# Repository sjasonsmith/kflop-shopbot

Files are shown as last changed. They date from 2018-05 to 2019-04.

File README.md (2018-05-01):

# kflop-shopbot
Custom KFLOP operations for a repowered ShopBot Buddy with speed controlled spindle.

**Caution: These scripts are not guaranteed to work on your machine.
Use at your own risk, and only with a full understanding of the functionality you are using.**

These scripts were developed for a ShopBot Buddy which has been repowered with a Dynomotion KFLOP Motion Controller. Refer to the following forum for a description of the conversion:

https://www.cnczone.com/forums/dynomotion-kflop-kanalog/310688-software.html

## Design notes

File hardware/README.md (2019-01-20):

# kflop-shopbot
EAGLE resources to create an interface board between the KMotion KFlop and the ShopBot Buddy.
This enables the conversion without modifying any existing electronics.

Board layout
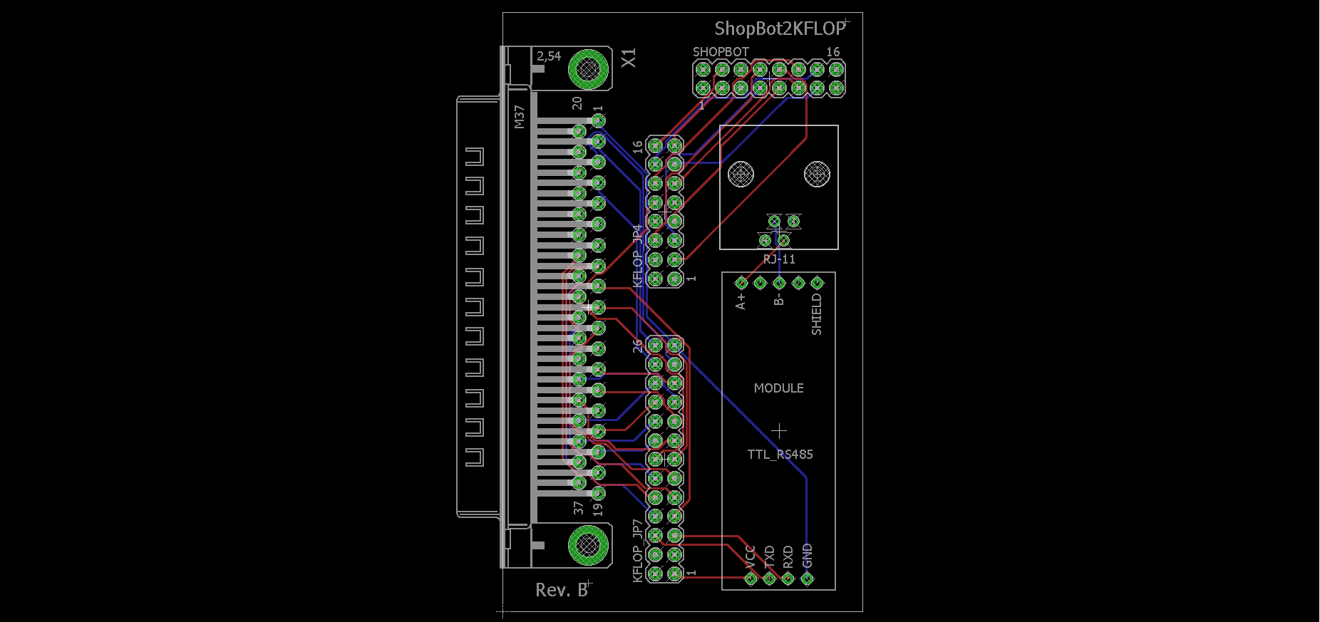
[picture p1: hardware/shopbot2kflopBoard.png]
Board Layout Image


Schematic
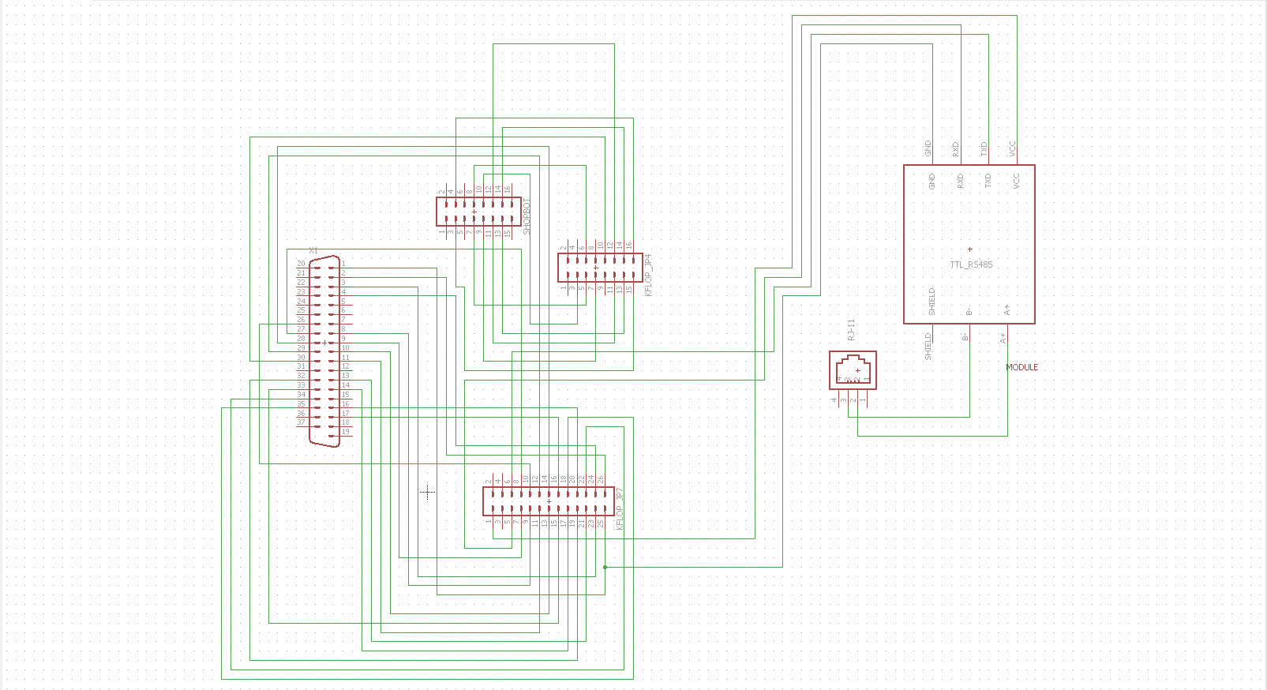
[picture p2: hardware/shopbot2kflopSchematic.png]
Schematic Image


Additional Information:

https://www.cnczone.com/forums/dynomotion-kflop-kanalog/310688-software.html

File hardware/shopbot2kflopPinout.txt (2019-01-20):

DB-37 Pin	Description           KFlop JP7 Pin	Description
-------------------------------------------------------------------
1		Ground			25		GND
2		Ground			26		GND
3		5V			23		VDD5
4		5V			24		VDD5
8		Input 3 (Y-Home)	9		IO2
9		Input 1 (Probe)		7		IO0
10		Input 7			13		IO6
11		Input 5 (Z-Home)	11		IO4
13		Step 4 (A-Axis)		21		IO14/STEP3
14		Step 2 (Y-Axis)		17		IO10/STEP1
16		Direction 3 (Z-Axis)	20		IO13/DIR2
17		Direction 1 (X-Axis)	16		IO9/DIR0
26		Input 4 (E-Stop)	10		IO3
27		Input 2 (X-Home)	8		IO1
28		Input 8			14		IO7
29		Input 6			12		IO5
30		All Windings Off	JP4 10		IO19 LVTTL
32		Step 3 (Z-Axis)		19		IO12/STEP2
33		Step 1 (X-Axis)		15		IO8/STEP0
34		Direction 4 (A-Axis)	22		IO15/DIR3
35		Direction 2 (Y-Axis)	18		IO11/DIR1

Left Ribbon 	Description           KFlop JP4 Pin	Description
-------------------------------------------------------------------
3  - Output 9					JP4 15	IO24 LVTTL
4  - Output 10					JP4 16	IO25 LVTTL
7  - Output 1 (Spindle 1 Relay Control)		JP4 5	IO16 LVTTL
8  - Output 2 (Spindle 2 Relay Control)		JP4 6	IO17 LVTTL				
9  - Output 3					JP4 7	IO18 LVTTL
10 - Output 4 (Master Spindle Relay Control)    JP4 3	VDD33 
11 - Output 5					JP4 11	IO20 LVTTL
12 - Output 6					JP4 12	IO21 LVTTL
13 - Output 7					JP4 13	IO22 LVTTL
14 - Output 8					JP4 14	IO23 LVTTL

RS-485 		Description           KFlop JP7 Pin	Description
--------------------------------------------------------------------
GND		Ground			JP7 25		GND
RXD		Receive			JP7 5		IO44 LVTTL UART
TXD		Transmitt		JP7 6		IO45 LVTTL UART
VCC		Vcc			JP7 1		VDD33

Universal CNC 4 Axis MPG - NOT PROOFED
Wire	Color		Function		Kflop JP6	
---------------------------------------------------------------------
1	Red		+5V MPG			1	VDD5	+5 Volts Output
2	Black		GND MPG			8	GND	Digital Ground
3	Yellow		A+ signal MPG		5	IO26 	Gen Purpose LVTTL I/O
4	Light Yellow	A- signal MPG
5	White		B+ Signal MPG		6	IO27 	Gen Purpose LVTTL I/O
6	Transparent	B- Signal MPG
7	Light red	LED +
8	Gray		LED -
9	Brown		X Axis select		7	IO28 	Gen Purpose LVTTL I/O
10	Orange		Y Axis select		10	IO29 	Gen Purpose LVTTL I/O
11	Light blue	Z Axis select		11	IO30 	Gen Purpose LVTTL I/O
12	Blue		4 Axis select
13	Dark green	X 1 Select		12	IO31 	Gen Purpose LVTTL I/O
14	Green		X10 Select		13	IO32 	Gen Purpose LVTTL I/O
15	Light green	X100 Select		14	IO33 	Gen Purpose LVTTL I/O
16	Purple		COM select		8	GND	Digital Ground
Shield			Shield wire
estop?						15	IO34 	Gen Purpose LVTTL I/O
estop?						16	IO35 	Gen Purpose LVTTL I/O

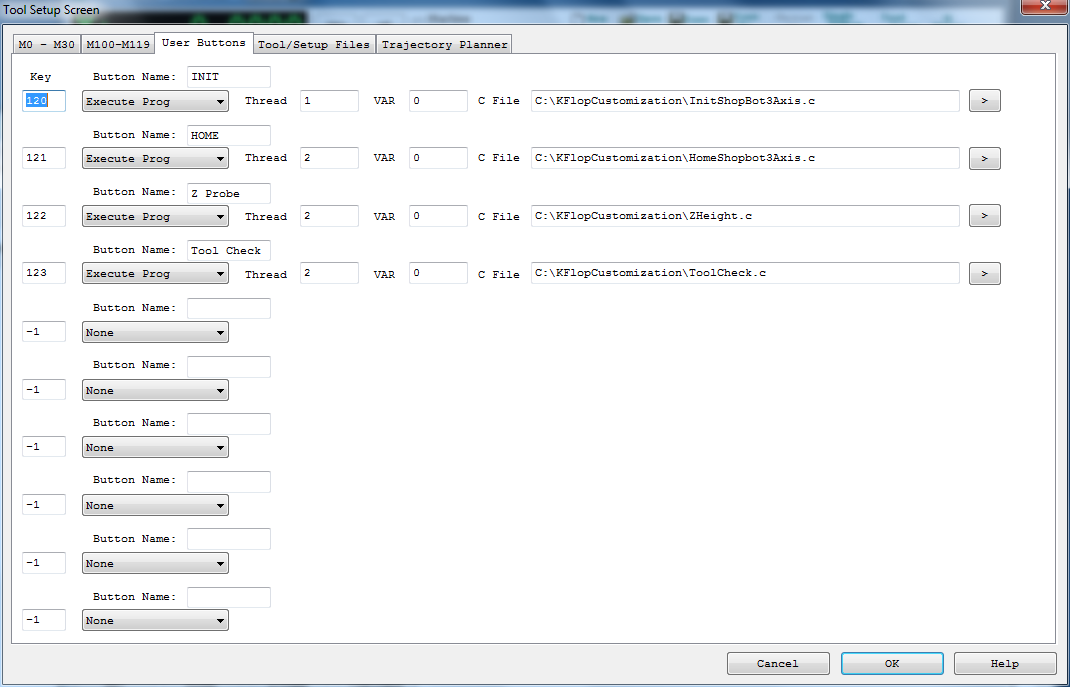
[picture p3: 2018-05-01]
images/UserButtons.PNG

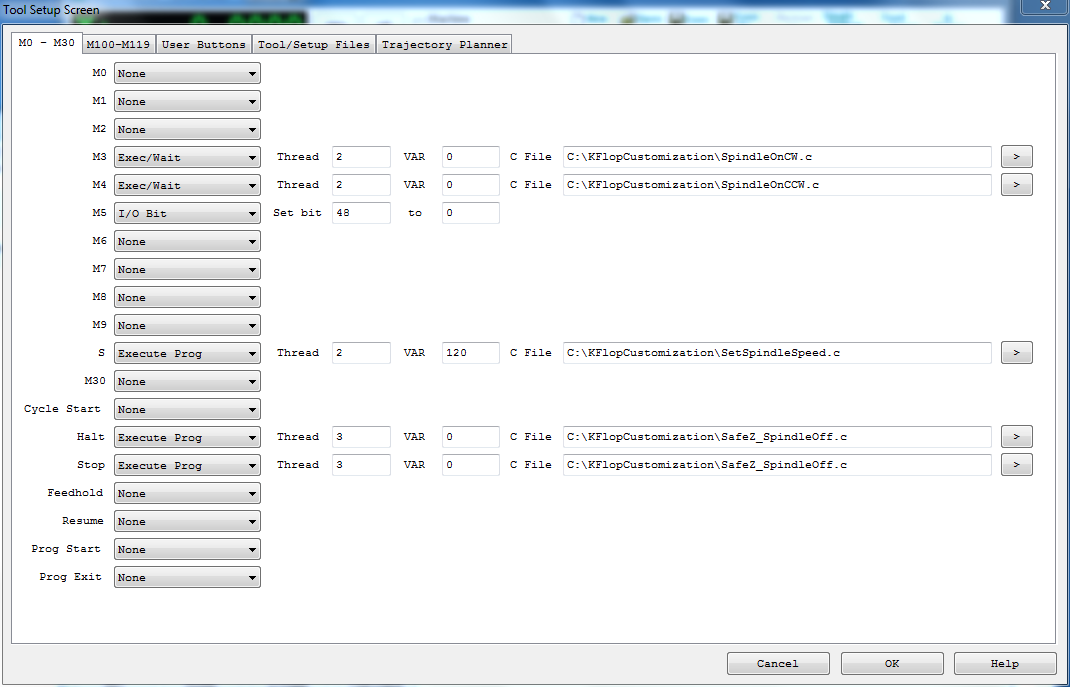
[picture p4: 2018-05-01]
images/M0-M30.PNG

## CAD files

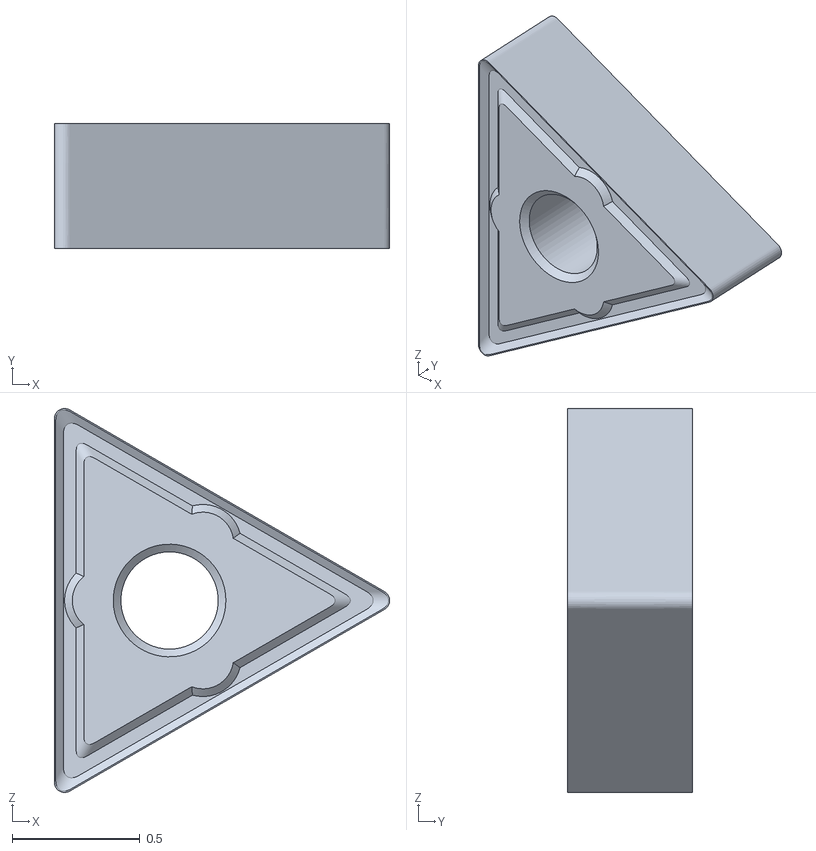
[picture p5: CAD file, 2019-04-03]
KMotionDataSnapshot/ToolImages/TNMG.obj
1.31 x 0.49 x 1.50

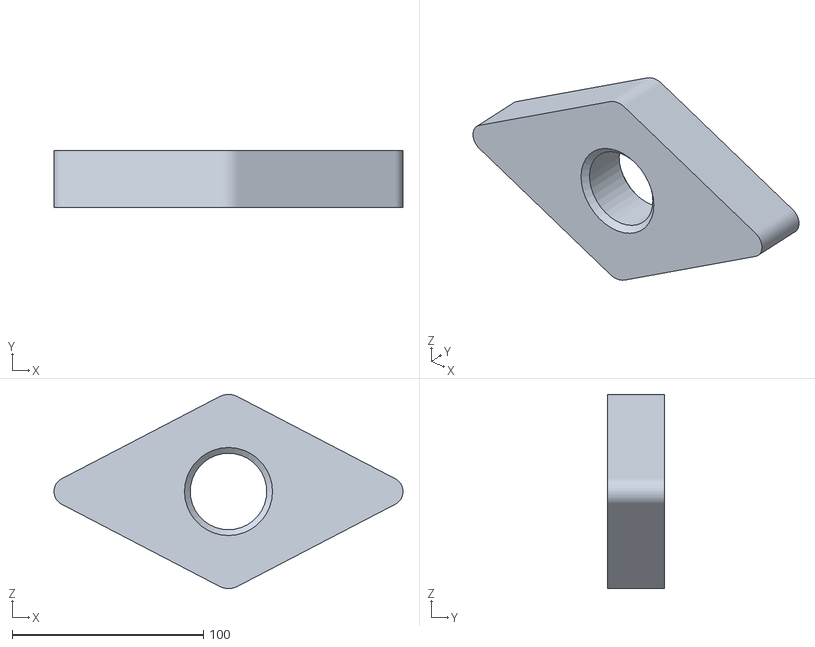
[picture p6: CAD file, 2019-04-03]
KMotionDataSnapshot/ToolImages/DCGT-1.obj
182.5 x 30.0 x 101.6

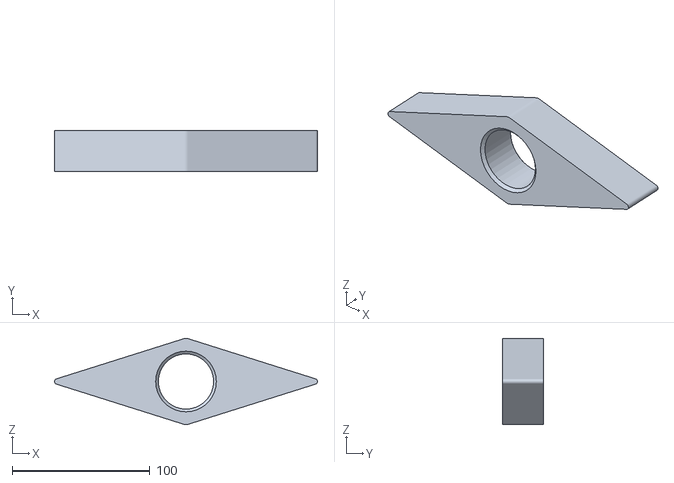
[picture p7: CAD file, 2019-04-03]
KMotionDataSnapshot/ToolImages/VNMG-1.obj
190.7 x 30.0 x 62.6

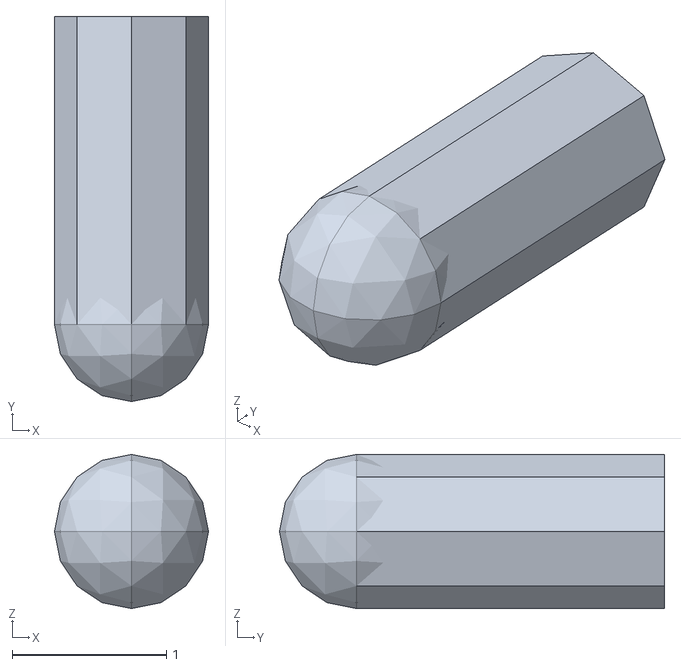
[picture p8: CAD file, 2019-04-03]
KMotionDataSnapshot/ToolImages/tooly.obj
1.00 x 2.50 x 1.00

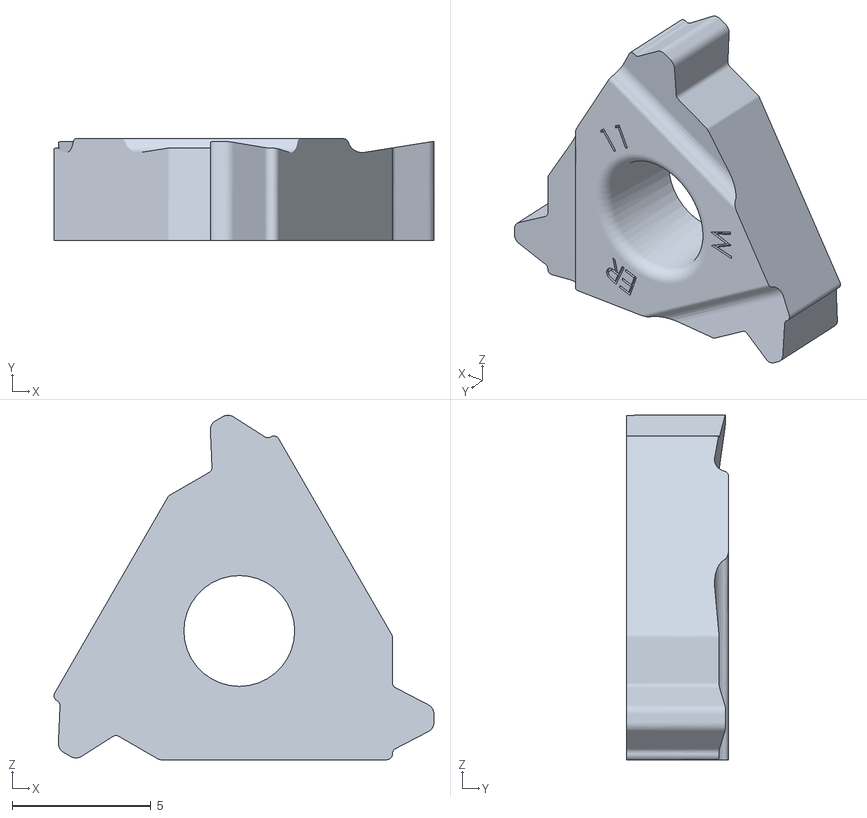
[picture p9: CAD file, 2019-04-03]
KMotionDataSnapshot/ToolImages/NPTF Front.obj
13.7 x 3.68 x 12.4

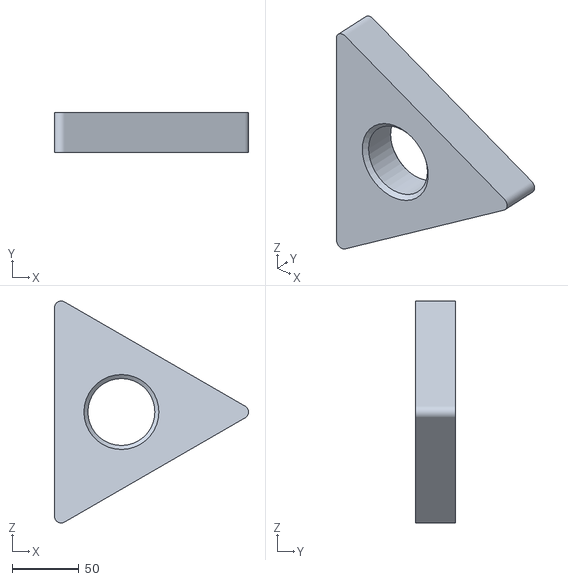
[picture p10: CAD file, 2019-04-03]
KMotionDataSnapshot/ToolImages/TNMG-1.obj
145.0 x 30.0 x 165.9

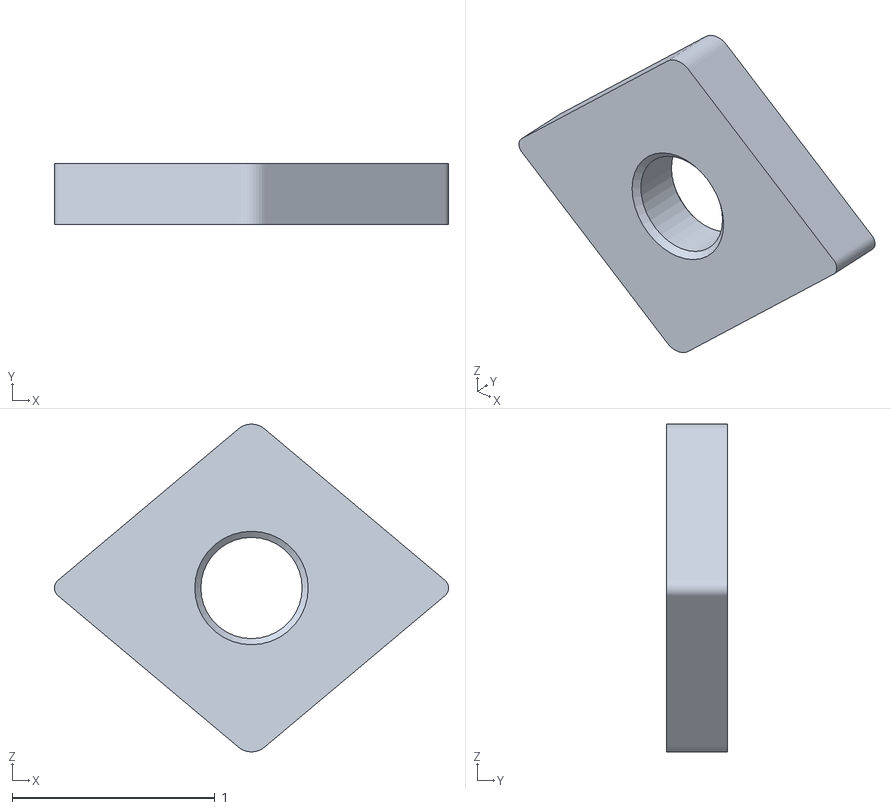
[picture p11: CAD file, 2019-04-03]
KMotionDataSnapshot/ToolImages/CNMG-1.obj
1.94 x 0.3 x 1.62

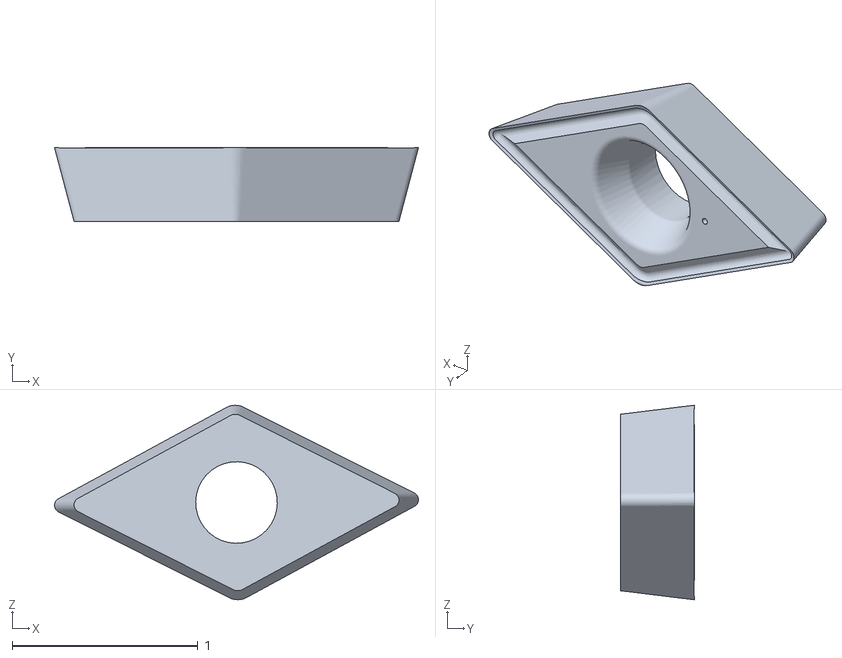
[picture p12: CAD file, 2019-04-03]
KMotionDataSnapshot/ToolImages/DCGT.obj
1.96 x 0.397 x 1.05

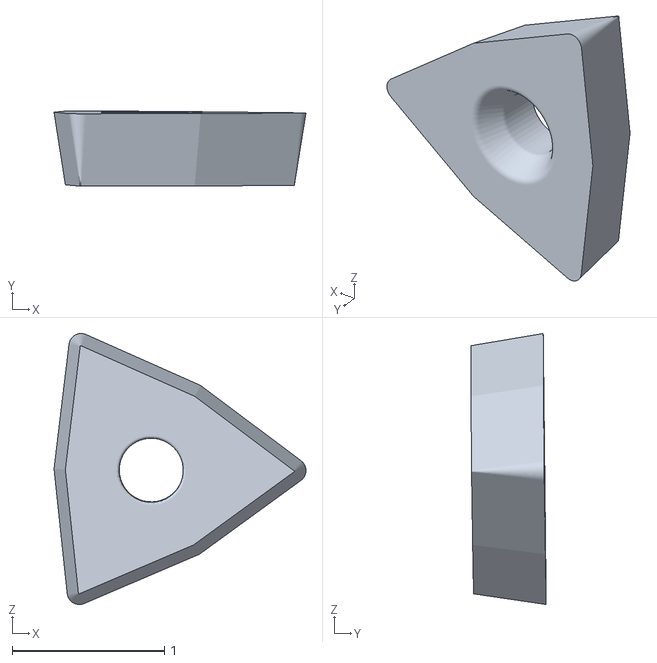
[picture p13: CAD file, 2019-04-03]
KMotionDataSnapshot/ToolImages/WNMG-1.obj
1.65 x 0.495 x 1.78

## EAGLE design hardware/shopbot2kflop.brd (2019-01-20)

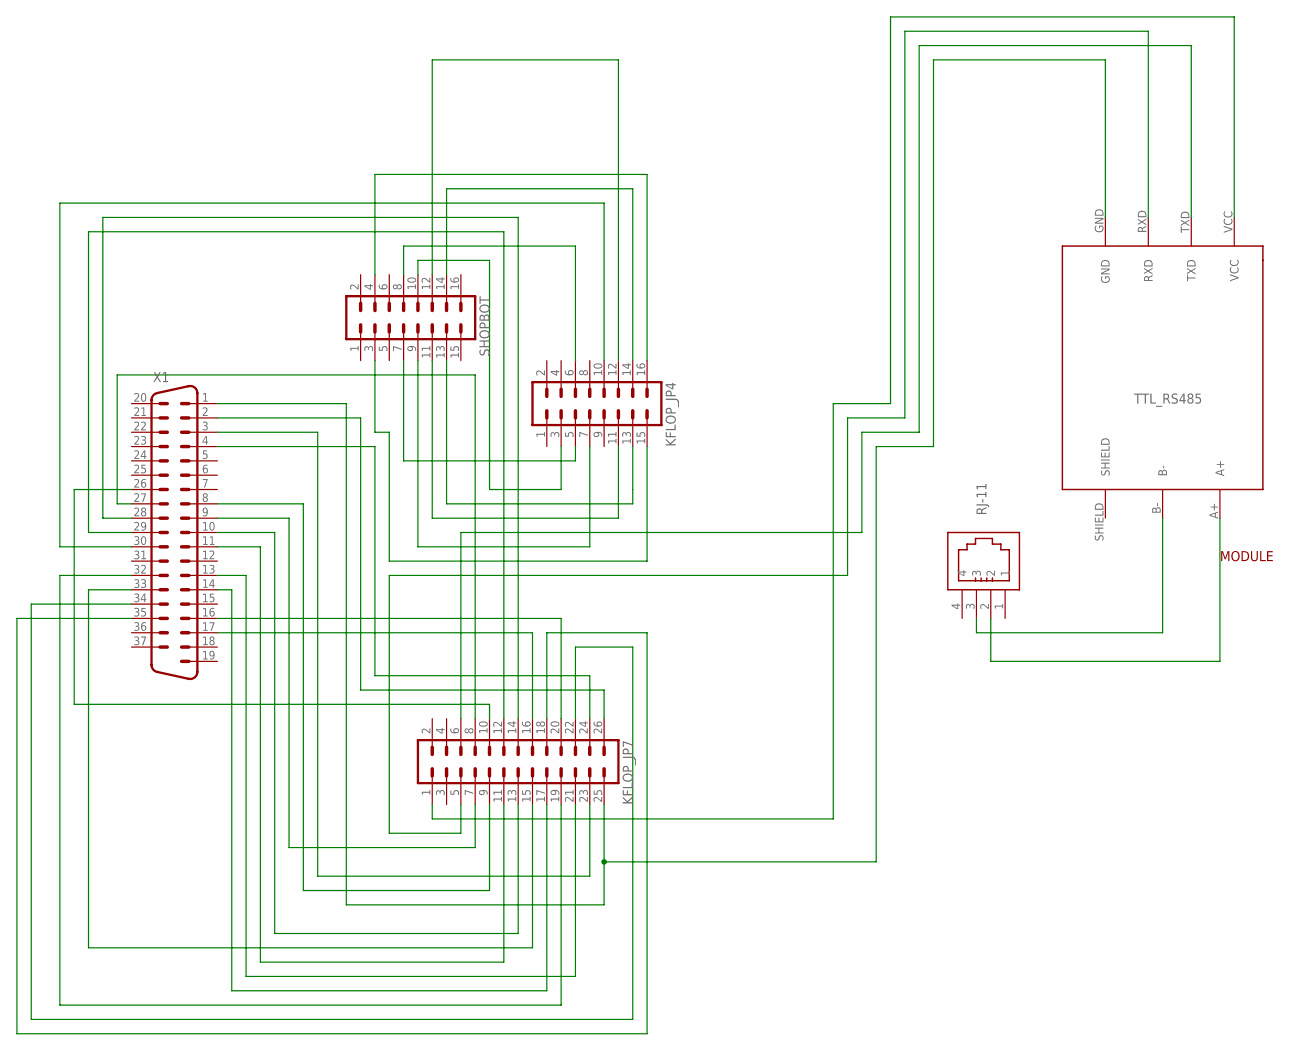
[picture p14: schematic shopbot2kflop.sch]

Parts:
KFLOP_JP4: MA08-2
KFLOP_JP7: MA13-2
MODULE: TTL_RS485
RJ-11: 615004144121
SHOPBOT: MA08-2
X1: M37HP

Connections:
unnamed: KFLOP_JP7.13, X1.10
unnamed: KFLOP_JP4.6, SHOPBOT.8
unnamed: KFLOP_JP7.18, X1.35
unnamed: KFLOP_JP7.5, MODULE.RXD
unnamed: KFLOP_JP7.26, X1.2
unnamed: KFLOP_JP7.6, MODULE.TXD
unnamed: KFLOP_JP4.5, SHOPBOT.7
unnamed: KFLOP_JP4.3, SHOPBOT.10
unnamed: KFLOP_JP4.15, SHOPBOT.3
unnamed: KFLOP_JP4.16, SHOPBOT.4
unnamed: KFLOP_JP4.7, SHOPBOT.9
unnamed: MODULE.B-, RJ-11.3
unnamed: KFLOP_JP7.23, X1.3
unnamed: KFLOP_JP7.24, X1.4
unnamed: KFLOP_JP7.9, X1.8
unnamed: KFLOP_JP7.7, X1.9
unnamed: KFLOP_JP7.1, MODULE.VCC
unnamed: KFLOP_JP7.11, X1.11
unnamed: KFLOP_JP7.21, X1.13
unnamed: KFLOP_JP7.17, X1.14
unnamed: KFLOP_JP7.20, X1.16
unnamed: KFLOP_JP7.16, X1.17
unnamed: KFLOP_JP7.10, X1.26
unnamed: KFLOP_JP7.8, X1.27
unnamed: KFLOP_JP7.14, X1.28
unnamed: KFLOP_JP7.12, X1.29
unnamed: KFLOP_JP4.10, X1.30
unnamed: KFLOP_JP7.19, X1.32
unnamed: KFLOP_JP7.15, X1.33
unnamed: KFLOP_JP7.22, X1.34
unnamed: KFLOP_JP4.11, SHOPBOT.11
unnamed: KFLOP_JP7.25, MODULE.GND, X1.1
unnamed: MODULE.A+, RJ-11.2
unnamed: KFLOP_JP4.12, SHOPBOT.12
unnamed: KFLOP_JP4.13, SHOPBOT.13
unnamed: KFLOP_JP4.14, SHOPBOT.14

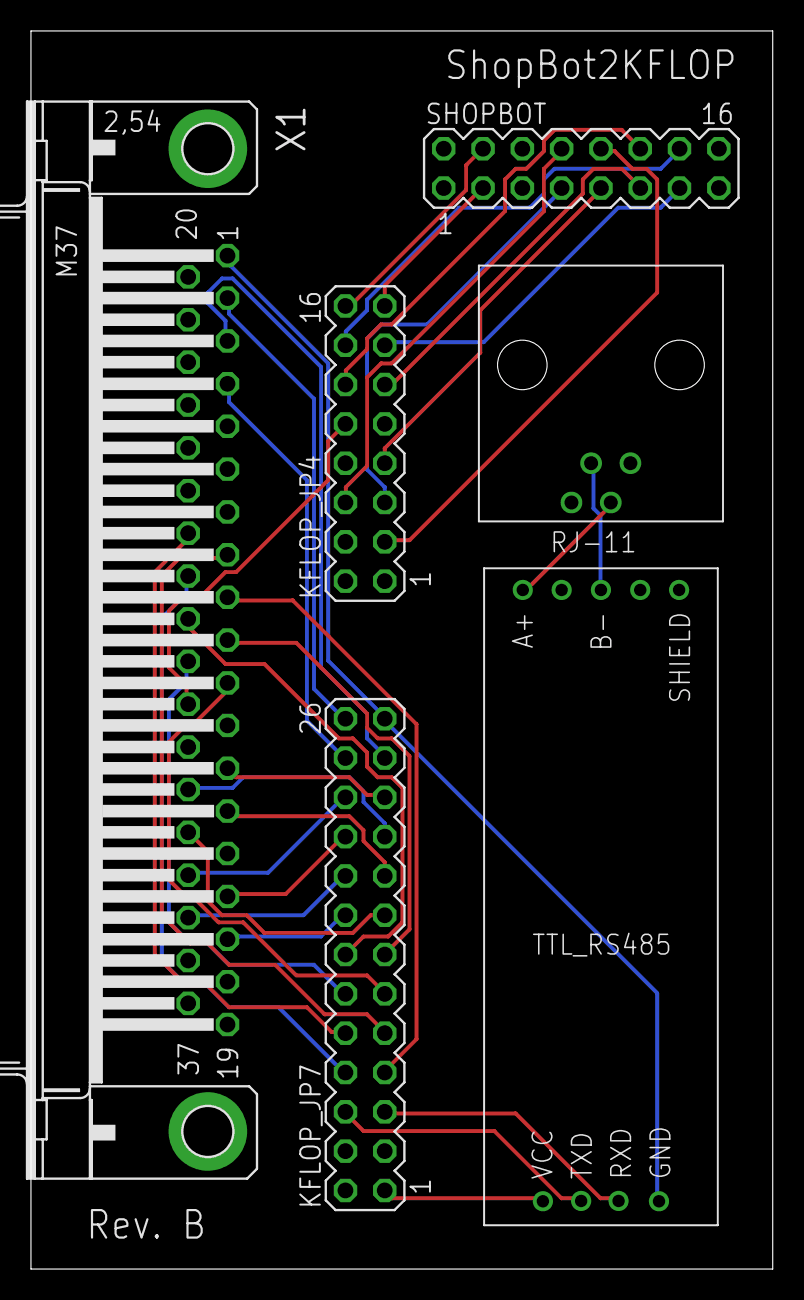
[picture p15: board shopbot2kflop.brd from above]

Board: 2 copper layers, 47.9 x 80.0 mm, 6 parts (0 on the bottom side), 36 nets.

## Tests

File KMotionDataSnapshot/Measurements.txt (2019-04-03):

5,5
1,1
-2,-2
0,0,-1.767822,-2.129132,-0.331770
0,1,-0.878572,-2.068192,-0.262691
0,2,0.036983,-1.979272,-0.234576
0,3,0.930314,-1.909252,-0.237177
0,4,1.836404,-1.805593,-0.236061
1,0,-1.774018,-1.155364,-0.219091
1,1,-0.882401,-1.073801,-0.179651
1,2,0.021794,-0.987806,-0.141523
1,3,0.918408,-0.885504,-0.130446
1,4,1.792961,-0.811495,-0.124016
2,0,-1.771149,-0.166872,-0.121132
2,1,-0.883159,-0.075746,-0.074570
2,2,0.007254,0.005231,-0.051105
2,3,0.889548,0.097292,-0.035076
2,4,1.762710,0.190093,-0.016807
3,0,-1.761705,0.784817,-0.086695
3,1,-0.885633,0.869580,-0.025417
3,2,0.001747,1.008045,0.017727
3,3,0.880585,1.108997,0.059038
3,4,1.742520,1.204385,0.058162
4,0,-1.729192,1.783193,0.021364
4,1,-0.871298,1.868678,0.054451
4,2,0.005017,1.979718,0.104414
4,3,0.878944,2.104289,0.141666
4,4,1.714383,2.182679,0.144980
0,0,5.739165,19.386162,1.883077
0,1,5.739165,19.386162,1.883077

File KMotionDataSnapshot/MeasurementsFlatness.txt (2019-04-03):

4,6
20,20
0,0
0,0,0,0,0
0,1,20,0,0
0,2,40,0,0
0,3,60,0,0
0,4,80,0,0
0,5,100,0,0
1,0,0,20,0
1,1,20,20,0
1,2,40,20,0
1,3,60,20,0
1,4,80,20,0
1,5,100,20,0
2,0,0,40,0
2,1,20,40,0
2,2,40,40,0
2,3,60,40,0.01
2,4,80,40,0
2,5,100,40,0
3,0,0,60,0
3,1,20,60,0
3,2,40,60,0
3,3,60,60,0
3,4,80,60,0
3,5,100,60,0

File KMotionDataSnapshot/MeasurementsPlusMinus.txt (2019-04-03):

2,2
1,1
-0.5,-0.5
0,0,-1, 0, 0
0,1, 0,-1, 0
1,0, 0, 1, 0
1,1, 1, 0, 0

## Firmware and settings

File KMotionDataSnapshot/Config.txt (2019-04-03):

Accel[0]= 4.000000000000000e+004
Accel[1]= 4.000000000000000e+005
Accel[2]= 4.000000000000000e+005
Accel[3]= 4.000000000000000e+005
Accel[4]= 4.000000000000000e+005
Accel[5]= 4.000000000000000e+005
Accel[6]= 4.000000000000000e+005
Accel[7]= 4.000000000000000e+005
D[0]= 0.000000000000000e+000
D[1]= 0.000000000000000e+000
D[2]= 0.000000000000000e+000
D[3]= 0.000000000000000e+000
D[4]= 0.000000000000000e+000
D[5]= 0.000000000000000e+000
D[6]= 0.000000000000000e+000
D[7]= 0.000000000000000e+000
FFAccel[0]= 0.000000000000000e+000
FFAccel[1]= 0.000000000000000e+000
FFAccel[2]= 0.000000000000000e+000
FFAccel[3]= 0.000000000000000e+000
FFAccel[4]= 0.000000000000000e+000
FFAccel[5]= 0.000000000000000e+000
FFAccel[6]= 0.000000000000000e+000
FFAccel[7]= 0.000000000000000e+000
FFVel[0]= 0.000000000000000e+000
FFVel[1]= 0.000000000000000e+000
FFVel[2]= 0.000000000000000e+000
FFVel[3]= 0.000000000000000e+000
FFVel[4]= 0.000000000000000e+000
FFVel[5]= 0.000000000000000e+000
FFVel[6]= 0.000000000000000e+000
FFVel[7]= 0.000000000000000e+000
I[0]= 0.000000000000000e+000
I[1]= 9.999999776482582e-003
I[2]= 9.999999776482582e-003
I[3]= 9.999999776482582e-003
I[4]= 0.000000000000000e+000
I[5]= 0.000000000000000e+000
I[6]= 0.000000000000000e+000
I[7]= 0.000000000000000e+000
Jerk[0]= 4.000000000000000e+005
Jerk[1]= 4.000000000000000e+006
Jerk[2]= 4.000000000000000e+006
Jerk[3]= 4.000000000000000e+006
Jerk[4]= 4.000000000000000e+006
Jerk[5]= 4.000000000000000e+006
Jerk[6]= 4.000000000000000e+006
Jerk[7]= 4.000000000000000e+006
MaxI[0]= 2.000000000000000e+002
MaxI[1]= 2.000000000000000e+002
MaxI[2]= 2.000000000000000e+002
MaxI[3]= 2.000000000000000e+002
MaxI[4]= 2.000000000000000e+002
MaxI[5]= 2.000000000000000e+002
MaxI[6]= 2.000000000000000e+002
MaxI[7]= 2.000000000000000e+002
MaxErr[0]= 1.000000000000000e+006
MaxErr[1]= 1.000000000000000e+006
MaxErr[2]= 1.000000000000000e+006
MaxErr[3]= 1.000000000000000e+006
MaxErr[4]= 2.000000000000000e+002
MaxErr[5]= 2.000000000000000e+002
MaxErr[6]= 2.000000000000000e+002
MaxErr[7]= 2.000000000000000e+002
MaxOutput[0]= 2.000000000000000e+002
MaxOutput[1]= 2.000000000000000e+002
MaxOutput[2]= 2.000000000000000e+002
MaxOutput[3]= 2.000000000000000e+002
MaxOutput[4]= 2.000000000000000e+002
MaxOutput[5]= 2.000000000000000e+002
MaxOutput[6]= 2.000000000000000e+002
MaxOutput[7]= 2.000000000000000e+002
DeadBandGain[0]= 1.000000000000000e+000
DeadBandGain[1]= 1.000000000000000e+000
DeadBandGain[2]= 1.000000000000000e+000
DeadBandGain[3]= 1.000000000000000e+000
DeadBandGain[4]= 1.000000000000000e+000
DeadBandGain[5]= 1.000000000000000e+000
DeadBandGain[6]= 1.000000000000000e+000
DeadBandGain[7]= 1.000000000000000e+000
DeadBandRange[0]= 0.000000000000000e+000
DeadBandRange[1]= 0.000000000000000e+000
DeadBandRange[2]= 0.000000000000000e+000
DeadBandRange[3]= 0.000000000000000e+000
DeadBandRange[4]= 0.000000000000000e+000
DeadBandRange[5]= 0.000000000000000e+000
DeadBandRange[6]= 0.000000000000000e+000
DeadBandRange[7]= 0.000000000000000e+000
BacklashAmount[0]= 0.000000000000000e+000
BacklashAmount[1]= 0.000000000000000e+000
BacklashAmount[2]= 0.000000000000000e+000
BacklashAmount[3]= 0.000000000000000e+000
BacklashAmount[4]= 0.000000000000000e+000
BacklashAmount[5]= 0.000000000000000e+000
BacklashAmount[6]= 0.000000000000000e+000
BacklashAmount[7]= 0.000000000000000e+000
BacklashRate[0]= 0.000000000000000e+000
BacklashRate[1]= 0.000000000000000e+000
BacklashRate[2]= 0.000000000000000e+000
BacklashRate[3]= 0.000000000000000e+000
BacklashRate[4]= 0.000000000000000e+000
BacklashRate[5]= 0.000000000000000e+000
BacklashRate[6]= 0.000000000000000e+000
BacklashRate[7]= 0.000000000000000e+000
P[0]= 1.000000000000000e+000
P[1]= 0.000000000000000e+000
P[2]= 0.000000000000000e+000
P[3]= 0.000000000000000e+000
P[4]= 2.000000029802322e-001
P[5]= 2.000000029802322e-001
P[6]= 2.000000029802322e-001
P[7]= 2.000000029802322e-001
StepSize[0]= 1.000000000000000e+003
StepSize[1]= 1.000000000000000e+003
StepSize[2]= 1.000000000000000e+003
StepSize[3]= 1.000000000000000e+004
StepSize[4]= 1.000000000000000e+005
StepSize[5]= 1.000000000000000e+000
StepSize[6]= 1.000000000000000e+000
StepSize[7]= 1.000000000000000e+000
AxisOutputMode[0]=6
AxisOutputMode[1]=6
AxisOutputMode[2]=6
AxisOutputMode[3]=6
AxisOutputMode[4]=5
AxisOutputMode[5]=5
AxisOutputMode[6]=5
AxisOutputMode[7]=5
AxisInputMode[0]=0
AxisInputMode[1]=0
AxisInputMode[2]=0
AxisInputMode[3]=1
AxisInputMode[4]=1
AxisInputMode[5]=1
AxisInputMode[6]=1
AxisInputMode[7]=1
AxisBacklashMode[0]=0
AxisBacklashMode[1]=0
AxisBacklashMode[2]=0
AxisBacklashMode[3]=0
AxisBacklashMode[4]=0
AxisBacklashMode[5]=0
AxisBacklashMode[6]=0
AxisBacklashMode[7]=0
StepTime[0]= 3.000000000000000e+000
StepTime[1]= 3.000000000000000e+000
StepTime[2]= 3.000000000000000e+000
StepTime[3]= 1.000000000000000e+000
StepTime[4]= 1.000000000000000e+000
StepTime[5]= 1.000000000000000e+000
StepTime[6]= 1.000000000000000e+000
StepTime[7]= 1.000000000000000e+000
Vel[0]= 4.000000000000000e+003
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

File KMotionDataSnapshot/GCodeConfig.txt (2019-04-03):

m_SetupFile=Default.set
m_ToolFile=Default.tbl
m_GeoFile=
m_Button0=INIT
m_Button1=HOME
m_Button2=1
m_Button3=2
m_Button4=3
m_Button5=4
m_Button6=5
m_Button7=6
m_Button8=7
m_Button9=8
m_BreakAngle= 2.000000000000000e+001
m_CollinearTol= 1.000000000000000e-003
m_CornerTol= 2.000000000000000e-003
m_FacetAngle= 1.000000000000000e+000
m_JogSpeed[0]= 1.000000000000000e+000
m_JogSpeed[1]= 1.000000000000000e+000
m_JogSpeed[2]= 1.000000000000000e+000
m_JogSpeed[3]= 1.000000000000000e+000
m_JogSpeed[4]= 1.000000000000000e+000
m_JogSpeed[5]= 1.000000000000000e+000
m_JogSlowPercent= 2.500000000000000e+001
m_HardwareFRORange= 0.000000000000000e+000
m_TPLookahead= 3.000000000000000e+000
m_RadiusC= 1.000000000000000e+000
m_RadiusB= 1.000000000000000e+000
m_RadiusA= 1.000000000000000e+000
m_MaxAccelC= 1.000000000000000e+001
m_MaxAccelB= 1.000000000000000e+001
m_MaxAccelA= 1.000000000000000e+001
m_MaxAccelX= 1.000000000000000e+001
m_MaxAccelY= 1.000000000000000e+001
m_MaxAccelZ= 1.000000000000000e+001
m_MaxVelC= 1.000000000000000e+000
m_MaxVelB= 1.000000000000000e+000
m_MaxVelA= 1.000000000000000e+000
m_MaxVelX= 1.000000000000000e+000
m_MaxVelY= 1.000000000000000e+000
m_MaxVelZ= 1.000000000000000e+000
m_CountsPerInchC= 1.000000000000000e+003
m_CountsPerInchB= 1.000000000000000e+003
m_CountsPerInchA= 1.000000000000000e+003
m_CountsPerInchX= 1.000000000000000e+003
m_CountsPerInchY= 1.000000000000000e+003
m_CountsPerInchZ= 1.000000000000000e+003
m_Step0= 1.000000000000000e-005
m_Step1= 1.000000000000000e-004
m_Step2= 1.000000000000000e-003
m_Step3= 1.000000000000000e-002
m_Step4= 1.000000000000000e-001
m_Step5= 1.000000000000000e+000
m_ReverseRZ=0
m_EnableGamePad=1
m_ZeroUsingFixtures=0
m_ToolLengthImmediately=0
m_ArcsToSegs=1
m_DisplayEncoder=0
m_Lathe=0
m_DiameterMode=0
m_XPosFront=0
m_SpindleType=0
m_SpindleAxis=4
m_SpindleUpdateTime= 1.000000000000000e-001
m_SpindleTau= 1.000000000000000e-001
m_SpindleCntsPerRev= 1.000000000000000e+003
Interpreter->McodeActions[0].Action=0
Interpreter->McodeActions[0].dParams[0]= 0.000000000000000e+000
Interpreter->McodeActions[0].dParams[1]= 0.000000000000000e+000
Interpreter->McodeActions[0].dParams[2]= 0.000000000000000e+000
Interpreter->McodeActions[0].dParams[3]= 0.000000000000000e+000
Interpreter->McodeActions[0].dParams[4]= 0.000000000000000e+000
Interpreter->McodeActions[0].String=
Interpreter->McodeActions[1].Action=0
Interpreter->McodeActions[1].dParams[0]= 0.000000000000000e+000
Interpreter->McodeActions[1].dParams[1]= 0.000000000000000e+000
Interpreter->McodeActions[1].dParams[2]= 0.000000000000000e+000
Interpreter->McodeActions[1].dParams[3]= 0.000000000000000e+000
Interpreter->McodeActions[1].dParams[4]= 0.000000000000000e+000
Interpreter->McodeActions[1].String=
Interpreter->McodeActions[2].Action=0
Interpreter->McodeActions[2].dParams[0]= 0.000000000000000e+000
Interpreter->McodeActions[2].dParams[1]= 0.000000000000000e+000
Interpreter->McodeActions[2].dParams[2]= 0.000000000000000e+000
Interpreter->McodeActions[2].dParams[3]= 0.000000000000000e+000
Interpreter->McodeActions[2].dParams[4]= 0.000000000000000e+000
Interpreter->McodeActions[2].String=
Interpreter->McodeActions[3].Action=0
Interpreter->McodeActions[3].dParams[0]= 0.000000000000000e+000
Interpreter->McodeActions[3].dParams[1]= 0.000000000000000e+000
Interpreter->McodeActions[3].dParams[2]= 0.000000000000000e+000
Interpreter->McodeActions[3].dParams[3]= 0.000000000000000e+000
Interpreter->McodeActions[3].dParams[4]= 0.000000000000000e+000
Interpreter->McodeActions[3].String=
Interpreter->McodeActions[4].Action=0
Interpreter->McodeActions[4].dParams[0]= 0.000000000000000e+000
Interpreter->McodeActions[4].dParams[1]= 0.000000000000000e+000
Interpreter->McodeActions[4].dParams[2]= 0.000000000000000e+000
Interpreter->McodeActions[4].dParams[3]= 0.000000000000000e+000
Interpreter->McodeActions[4].dParams[4]= 0.000000000000000e+000
Interpreter->McodeActions[4].String=
Interpreter->McodeActions[5].Action=0
Interpreter->McodeActions[5].dParams[0]= 0.000000000000000e+000
Interpreter->McodeActions[5].dParams[1]= 0.000000000000000e+000
Interpreter->McodeActions[5].dParams[2]= 0.000000000000000e+000
Interpreter->McodeActions[5].dParams[3]= 0.000000000000000e+000
Interpreter->McodeActions[5].dParams[4]= 0.000000000000000e+000
Interpreter->McodeActions[5].String=
Interpreter->McodeActions[6].Action=0
Interpreter->McodeActions[6].dParams[0]= 0.000000000000000e+000
Interpreter->McodeActions[6].dParams[1]= 0.000000000000000e+000
Interpreter->McodeActions[6].dParams[2]= 0.000000000000000e+000
Interpreter->McodeActions[6].dParams[3]= 0.000000000000000e+000
Interpreter->McodeActions[6].dParams[4]= 0.000000000000000e+000
Interpreter->McodeActions[6].String=
Interpreter->McodeActions[7].Action=0
Interpreter->McodeActions[7].dParams[0]= 0.000000000000000e+000
Interpreter->McodeActions[7].dParams[1]= 0.000000000000000e+000
Interpreter->McodeActions[7].dParams[2]= 0.000000000000000e+000
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

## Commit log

2016-05-18 Initial checkin of MosbusMaster
    This is intended for an I/O expander, we will need to modify it to talk to
    our spindle.
2016-05-19 Jason's hacky version which will turn on the spindle
2016-05-20 Add simple program to fake setting spindle speed
2016-05-27 Disable Modbus I/O and talk between threads
    SetSpindleSpeed will set a desired speed, and wait until the modbus master
    thread echoes the value back.
2016-05-27 Print status every 5 second
2016-05-27 Add loops for spindle on/off using virtual bits
2016-05-27 Use virtual bits to control spindle state. Does not yet control speed.
2016-05-27 Working ZHeight probe
2016-05-27 Launch modbus thread from Init thread.
2016-05-27 Home Z axis before X and Y.
2016-05-27 Add commands that start spindle then wait 4 second.
2018-05-01 Modify soft limit for new bed height. Replaced MDF bed with aluminum and need more travel range.
    [HomeShopbot3Axis.c]
2018-06-15 Move ModbusMaster to thread 1
    This allows the thread to keep running when stop is pressed so that it can
    be used to stop the spindle.
2018-06-15 Add snapshot of data folder, which stores configuration
    [CNMG-1.obj, Config.txt, DCGT-1.obj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]
2018-06-15 Add a hack to stop the spindle when INIT is re-run
2019-01-20 Add Eagle resources for the interface board used This avoided modifications to the original ShopBot controller, by allowing direct connections to the KFlop.
    [shopbot2kflop.brd, shopbot2kflop.sch]

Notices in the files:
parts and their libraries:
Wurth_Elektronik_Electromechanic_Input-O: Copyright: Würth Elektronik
